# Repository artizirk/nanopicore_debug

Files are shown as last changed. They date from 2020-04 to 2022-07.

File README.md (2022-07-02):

# NanoPI NEO Core Debug shield

This shield provides one USB A and a uart0 via ch340 chip on seperate Micro USB connector

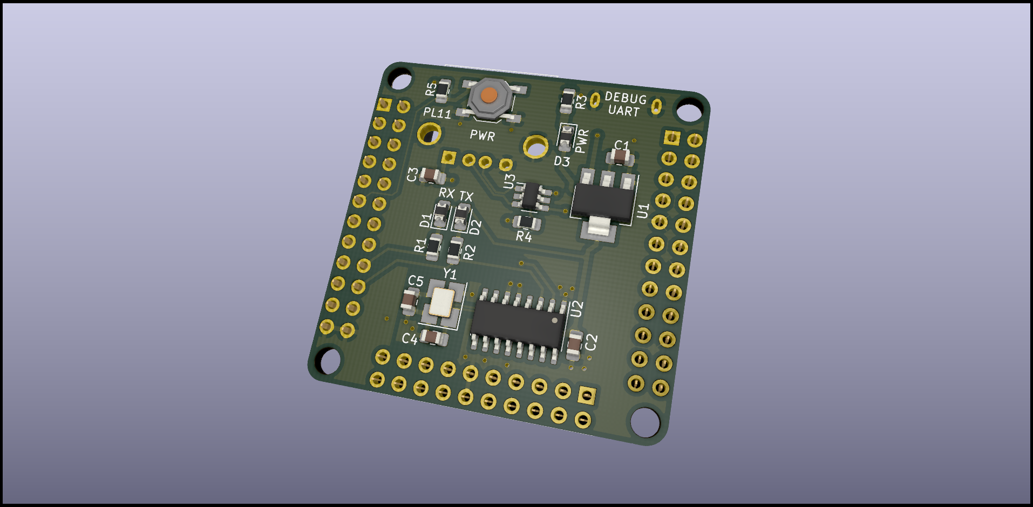
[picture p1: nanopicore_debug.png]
Board


### Armbian Device Tree overlay for power off button on GPIO PL11

gpio-button.dts file contains the overlay. Follow [Armbian docs] to apply it.

[Armbian docs]: https://docs.armbian.com/User-Guide_Allwinner_overlays/

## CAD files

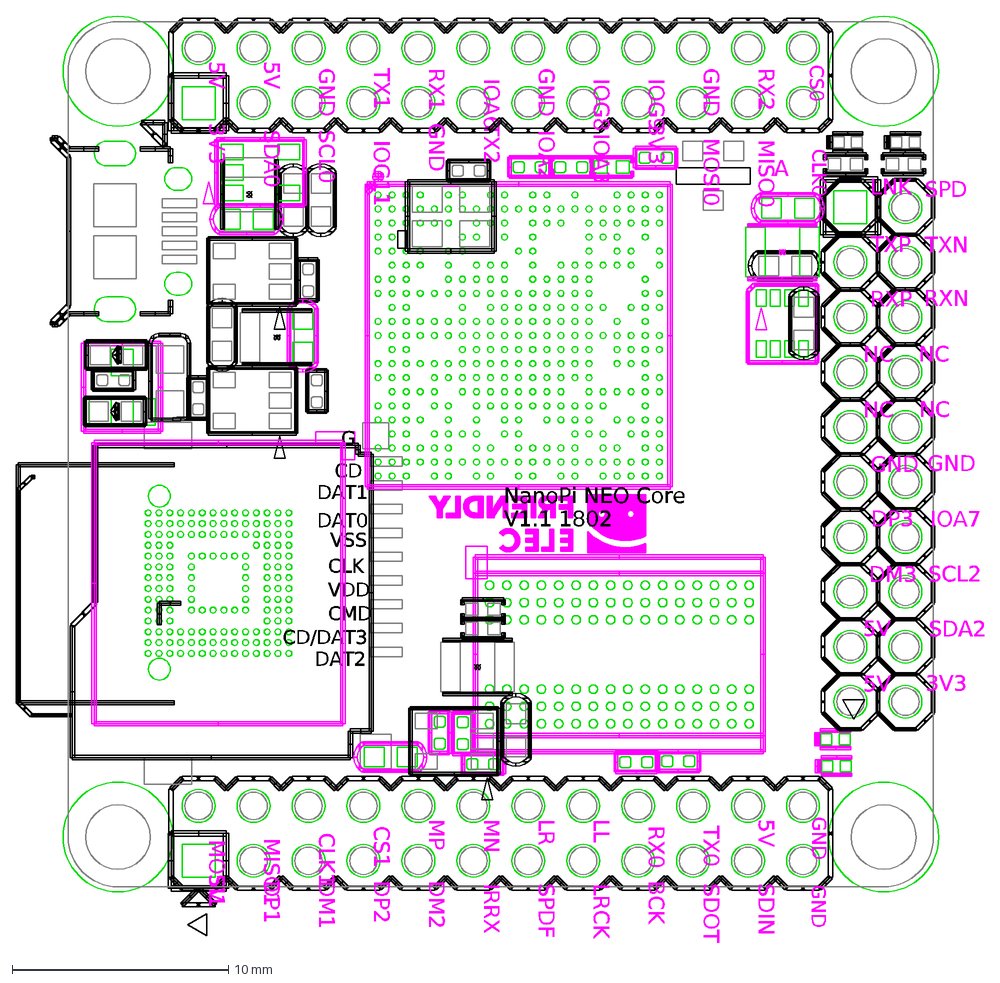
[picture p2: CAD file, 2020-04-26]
datasheet/NanoPi_NEO_Core-1.1_pcb-Dim.dxf
G
CD
DAT1
DAT0
VSS
CLK
VDD
CMD
CD/DAT3
DAT2
5V
CS1
CLK1
MISO1
MOSI1
DP1
DM1
DP2
DM2
IRRX
SPDF
LRCK
BCK
SDOT
SDIN
GND
NC
3V3
SDA2
DM3
SCL2
DP3
IOA7
RXP
RXN
TXP
TXN
LNK
SPD
SDA0
SCL0
IOG11
TX1
RX1
TX2
IOA2
IOA3
IOA6
IOG8
IOG9
MOSI0
MISO0
RX2
CLK0
CS0
V1.1 1802
RX0
TX0
LL
LR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

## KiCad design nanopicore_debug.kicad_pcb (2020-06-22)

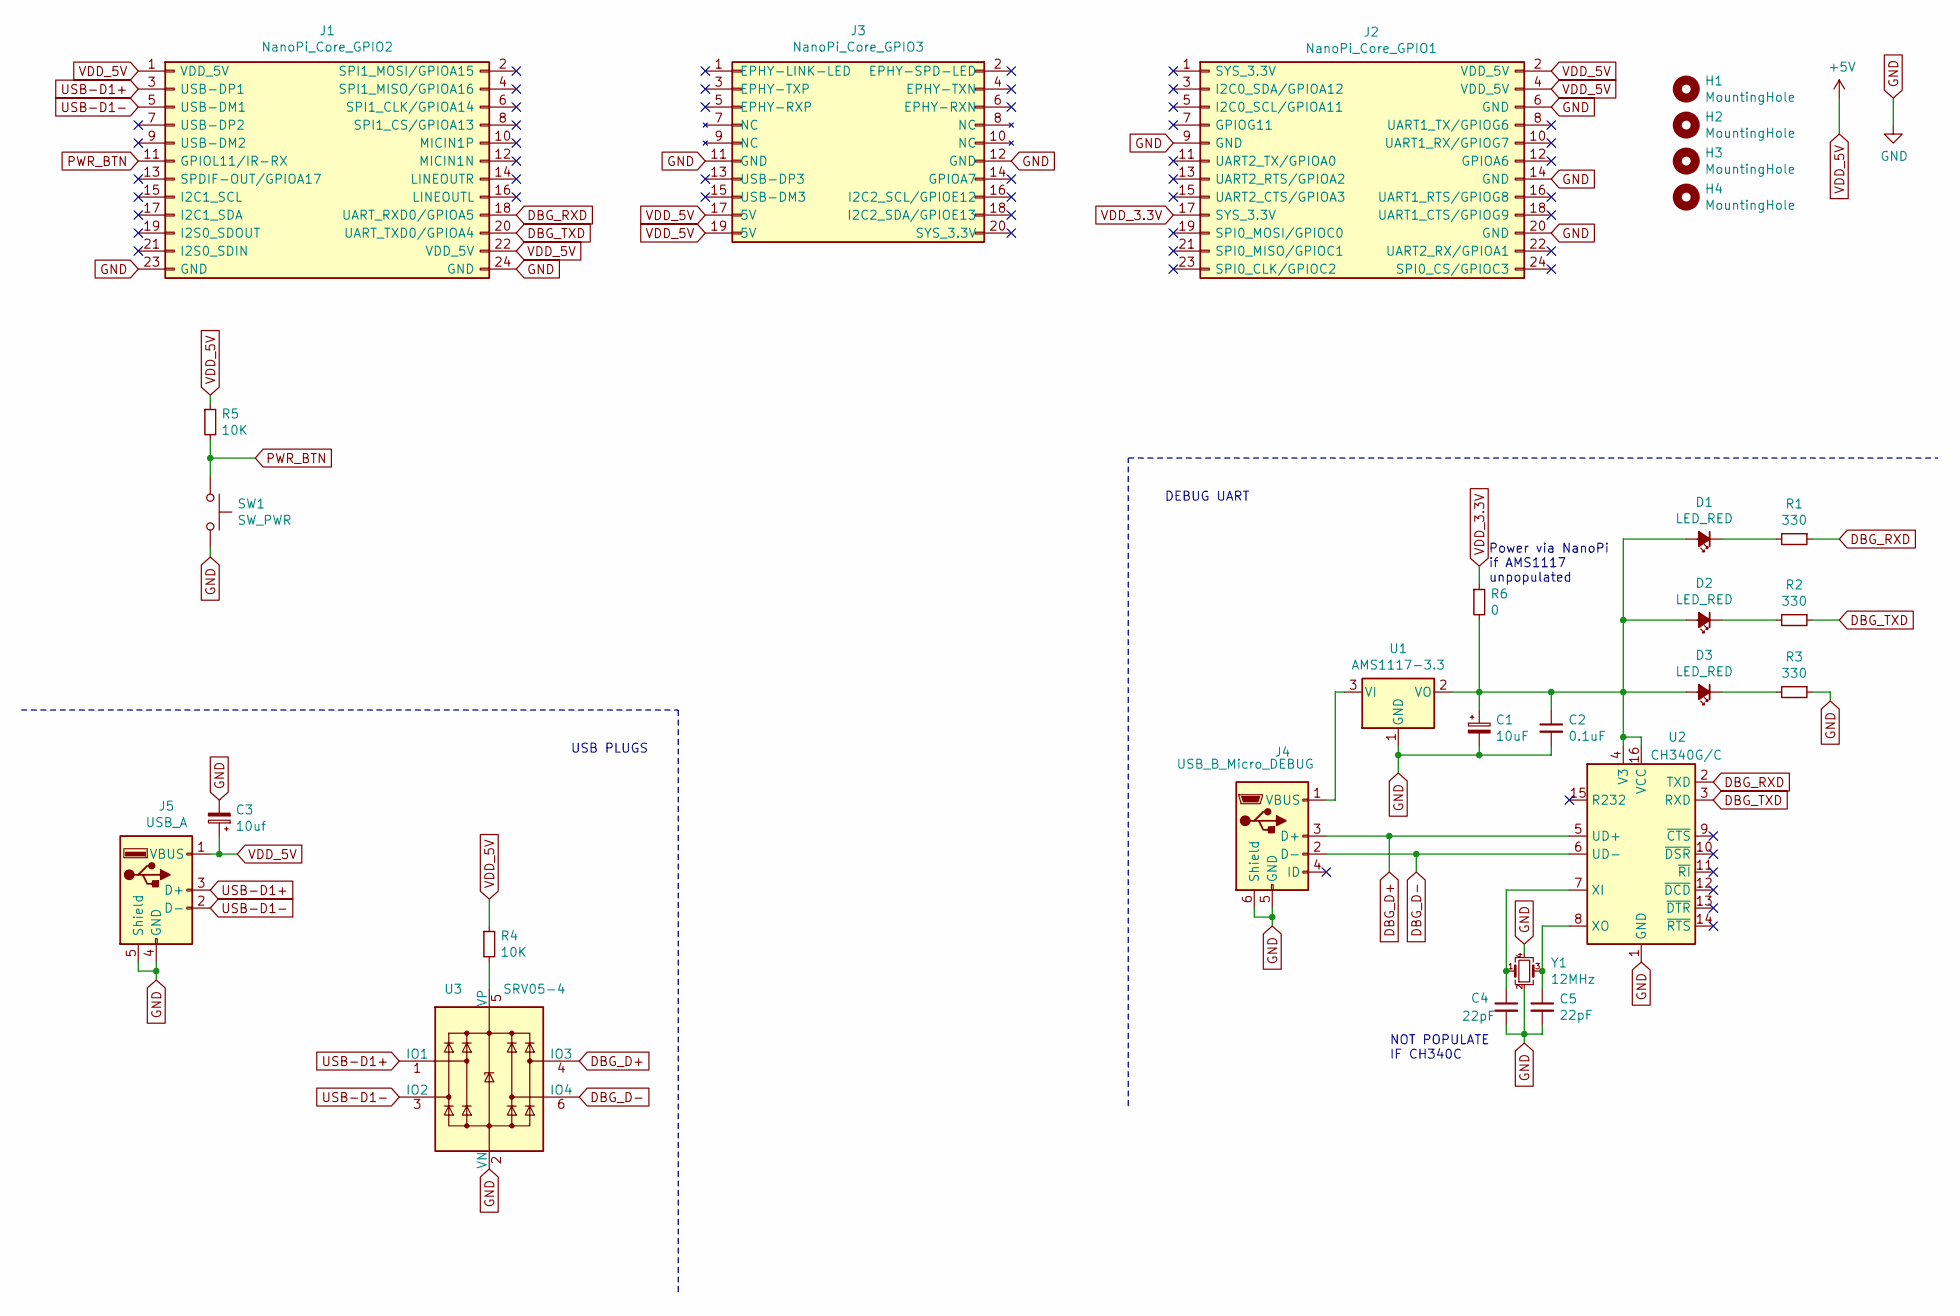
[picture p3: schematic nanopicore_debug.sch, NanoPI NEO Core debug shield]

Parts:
C1: 10uF; C_0805_2012Metric_Pad1.15x1.40mm_HandSolder
C2: 0.1uF; C_0805_2012Metric_Pad1.15x1.40mm_HandSolder
C3: 10uf; C_0805_2012Metric_Pad1.15x1.40mm_HandSolder
C4, C5: 22pF; C_0805_2012Metric_Pad1.15x1.40mm_HandSolder
D1, D2, D3: LED_RED; D_0805_2012Metric_Pad1.15x1.40mm_HandSolder; LCSC C84256
H1, H2, H3, H4: MountingHole; MountingHole_3mm
J1: NanoPi_Core_GPIO2; PinSocket_2x12_P2.54mm_Vertical
J2: NanoPi_Core_GPIO1; PinSocket_2x12_P2.54mm_Vertical
J3: NanoPi_Core_GPIO3; PinSocket_2x10_P2.54mm_Vertical
J4: USB_B_Micro_DEBUG; USB_Micro-B_GCT_USB3076-30-A; LCSC C393940
J5: USB_A; USB_A_Stewart_SS-52100-001_Horizontal; LCSC C2345
R1: 330; R_0805_2012Metric_Pad1.15x1.40mm_HandSolder; LCSC C17630
R2, R3: 330; R_0805_2012Metric_Pad1.15x1.40mm_HandSolder
R4, R5: 10K; R_0805_2012Metric_Pad1.15x1.40mm_HandSolder
R6: 0; R_0805_2012Metric_Pad1.15x1.40mm_HandSolder
SW1: SW_PWR; SW_SPST_TL3342; LCSC C388295
U1: AMS1117-3.3; SOT-223-3_TabPin2; LCSC C6186
U2: CH340G/C; SOIC-16_3.9x9.9mm_P1.27mm; LCSC C84681
U3: SRV05-4; SOT-23-6_Handsoldering; LCSC C85364
Y1: 12MHz; Crystal_SMD_3225-4Pin_3.2x2.5mm_HandSoldering; LCSC C9002

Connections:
DBG_D+: J4.3 (D+), U2.5 (UD+), U3.4 (IO3)
DBG_D-: J4.2 (D-), U2.6 (UD-), U3.6 (IO4)
DBG_RXD: J1.18 (UART_RXD0/GPIOA5), R1.1, U2.2 (TXD)
DBG_TXD: J1.20 (UART_TXD0/GPIOA4), R2.1, U2.3 (RXD)
GND: C1.2, C2.2, C3.2, C4.2, C5.2, J1.23 (GND), J1.24 (GND), J2.6 (GND), J2.9 (GND), J2.14 (GND), J2.20 (GND), J3.11 (GND), J3.12 (GND), J4.5 (GND), J4.6 (Shield), J5.4 (GND), J5.5 (Shield), R3.1, SW1.2, U1.1 (GND), U2.1 (GND), U3.2 (VN), Y1.2, Y1.4
unnamed: C1.1, C2.1, D1.2 (A), D2.2 (A), D3.2 (A), R6.2, U1.2 (VO), U2.4 (V3), U2.16 (VCC)
unnamed: C4.1, U2.7 (XI), Y1.1
unnamed: C5.1, U2.8 (XO), Y1.3
unnamed: D1.1 (K), R1.2
unnamed: D2.1 (K), R2.2
unnamed: D3.1 (K), R3.2
unnamed: J4.1 (VBUS), U1.3 (VI)
unnamed: R4.2, U3.5 (VP)
PWR_BTN: J1.11 (GPIOL11/IR-RX), R5.2, SW1.1
USB-D1+: J1.3 (USB-DP1), J5.3 (D+), U3.1 (IO1)
USB-D1-: J1.5 (USB-DM1), J5.2 (D-), U3.3 (IO2)
VDD_3.3V: J2.17 (SYS_3.3V), R6.1
VDD_5V: C3.1, J1.1 (VDD_5V), J1.22 (VDD_5V), J2.2 (VDD_5V), J2.4 (VDD_5V), J3.17 (5V), J3.19 (5V), J5.1 (VBUS), R4.1, R5.1

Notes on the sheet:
USB PLUGS
DEBUG UART
NOT POPULATE IF CH340C
Power via NanoPi if AMS1117 unpopulated

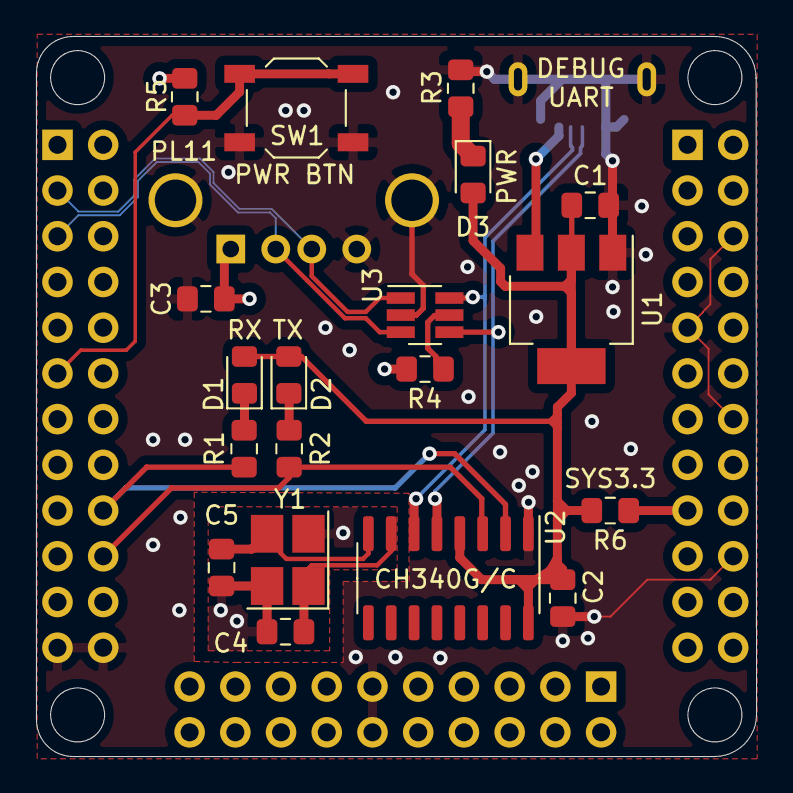
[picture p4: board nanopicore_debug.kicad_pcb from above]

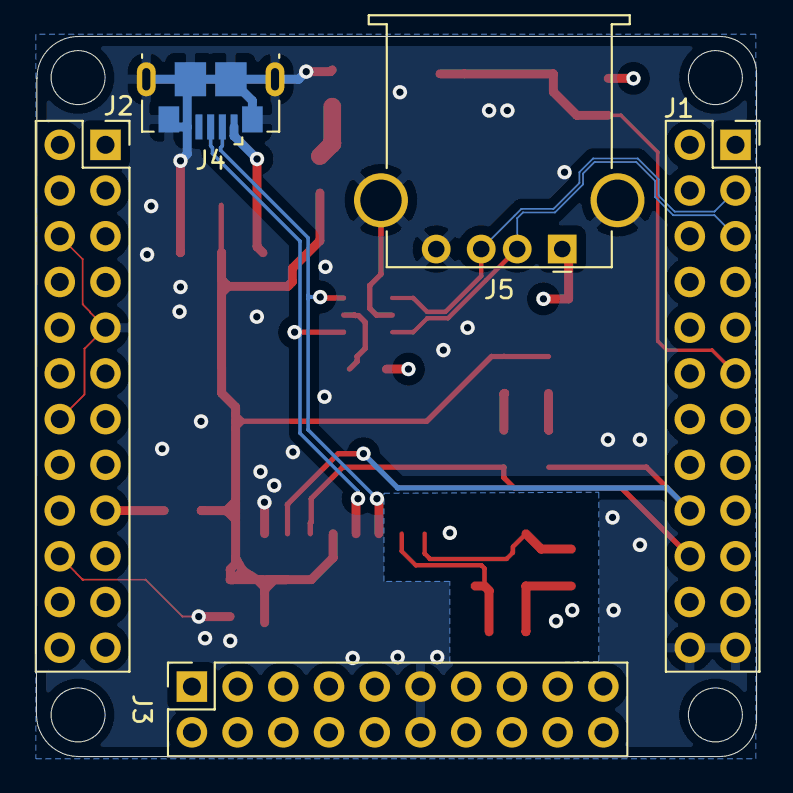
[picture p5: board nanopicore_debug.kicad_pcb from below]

Board: 4 copper layers, 40.0 x 40.0 mm, 28 parts (5 on the bottom side), 18 nets.

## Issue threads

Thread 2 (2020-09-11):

MicroUSB footprint is wrong

artizirk, 2020-09-11:
Currently using wrong footprint for https://lcsc.com/product-detail/USB-Connectors_SHOU-HAN-MICRO5-9mmusb_C393940.html

bending the connector leads sorta works but is not ideal

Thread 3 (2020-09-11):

power on led is too bright

artizirk, 2020-09-11:
330 ohm is still too small, need to make it larger to make the led dimmer

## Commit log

2020-04-26 Exports and initial BOM
    [BOM_nanopicore_debug.csv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]
2020-06-21 Add 0R resistor to power CH340 from NanoPi
    [nanopicore_debug-B_Cu.gbr, nanopicore_debug-B_Mask.gbr, nanopicore_debug-B_Paste.gbr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]
2020-06-22 Update BOM
    [BOM_nanopicore_debug.csv, nanopicore_debug.kicad_pcb, nanopicore_debug.sch]
2022-07-02 add device tree overlay
